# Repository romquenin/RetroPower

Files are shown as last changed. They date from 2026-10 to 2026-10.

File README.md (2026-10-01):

# RetroPower

Home Assistant-controlled power module for retro consoles, built around an ESP32-C3 — 2-layer PCB (KiCad), with a relay that emulates the console's power button for remote on/off.

## Two PCB versions

### `hardware/integrated/` — integrated version (recommended)
The ESP32-C3-Zero module (Waveshare, 18 castellated pins) is **soldered directly to the back of the PCB** — no flying wires. The antenna ends up on the outer edge of the board, completely clear of any copper/metal on both sides, for the best possible WiFi/Bluetooth reception.

- Dimensions: 53.335 x 32.75 mm
- Official KiCad DRC: 0 errors / 0 warnings (v4)
- See `README.md` in this folder for the changelog and the pin-spacing verification procedure to run before soldering the module for good.

### `hardware/compact/` — compact version (fallback)
The ESP32-C3-Zero module is connected via flying wires (not soldered directly onto the PCB). Immune to dimensional variation between modules — useful as a fallback if the integrated version ever runs into a physical compatibility issue.

- Dimensions: 40.45 x 32.75 mm
- Official KiCad DRC: 0 errors / 0 warnings (v11)
- See `README.md` and `WIRING.md` in this folder.

Each folder contains: the `.kicad_pcb`/`.kicad_pro` files, the gerbers (folder + zip), the component position file (`_pos.csv`), the BOM (`BOM.csv`), a rendered image of the routed board, and a `README.md` explaining the design choices.

## Bill of materials

Full per-reference BOM (with placement notes) is in each version's own `BOM.csv` (`hardware/integrated/BOM.csv` / `hardware/compact/BOM.csv`). Same components and values on both versions, except J1 (compact version only, header for the flying wires to the ESP32) and the ESP32 module itself (soldered directly on the integrated version, wired via J1 on the compact one).

**On the PCB:**

| Ref | Part | Package | Notes |
|---|---|---|---|
| U1 | ESP32-C3-Zero (Waveshare) | 18-pin castellated module, 2.54mm pitch | Integrated version only — soldered to the back of the PCB |
| K1 | HFD2/003-M-L2-D (Hongfa) | DIP-16 (10 real pins) | Bistable 2xRT relay |
| Q1, Q2 | AO3400A | SOT-23 | N-channel MOSFET |
| D1, D2 | 1N4148WS | SOD-123 | Flyback diodes (relay coils) |
| D3 | 1N5819WS | SOD-123 | Reverse-polarity protection on RAW_IN |
| R1, R2 | 100R | 0805, 1/4W 5% | Series gate resistors |
| R3, R4 | 10k | 0805, 1/4W 5% | Gate pulldowns |
| C1 | 100µF / 16V | SMD electrolytic, 6.3x5.4mm | — |
| C2 | 100nF | 0805 ceramic | HF decoupling on 3V3 |
| J1–J6 | 2.54mm pin headers | 2 to 5 pins, vertical | See each version's wiring notes |

**Off the PCB (external, per console):**

- A buck converter module (raw 12V/8V → regulated 3.3V) — any small off-the-shelf buck board rated for the console's raw voltage works; test it unloaded before wiring it in.
- Hookup wire:
  - **Power lines** (raw 12V/8V to/from the buck, regulated 3V3 to J2): 0.5mm²/20-21AWG is plenty for these currents.
  - **Signal/GPIO lines** (console switch tap to J4/J5, POWER_SENSE tap to J6): thinner wire is fine here, e.g. 30AWG — negligible current, easier to route inside the console's case.

## Firmware

`firmware/retropower_template.yaml` — generic ESPHome template, to be duplicated for each console (change `device_name` / `friendly_name`). Pinout used:

- GPIO0 — `POWER_SENSE` (reads the console's 3V3 rail)
- GPIO3 — `RELAY_SET` (pulse → turns on, via Q1)
- GPIO10 — `RELAY_RESET` (pulse → turns off, via Q2)

## Generation scripts (KiCad / Python)

`scripts/` contains the Python scripts (using the `pcbnew` API) used to generate and route each board, plus the verification scripts (clearance, holes, connectivity, board-edge clearance, silkscreen, component-body overlap) used alongside KiCad's official DRC.

- `scripts/integrated/`: `build_integrated.py` (placement + footprints), `route_integrated.py` (initial routing), `fix_net_integrated.py` (targeted routing fixes)
- `scripts/compact/`: `build_compact_v3.py`, `route_grid_compact5.py`
- `scripts/checks/`: verification scripts shared by both versions

Requires KiCad 7 (headless `pcbnew` API) and Python 3.

## How it works

The module emulates pressing the console's power button through two separate pulses (SET/RESET) driven by two MOSFETs (Q1/Q2) that control the two coils of a bistable relay (K1) — the relay stays in the chosen state with no continuous power draw. A sense tap (`POWER_SENSE`) lets the ESP32 read the console's actual power state for Home Assistant.

## Power supply

The buck converter (console's raw 12V/8V → regulated 3.3V) is **external**, not integrated onto the PCB. See each version's `README.md`/`WIRING.md` for the exact wiring (`J2` = regulated 3.3V input, `J3` = raw tap + reverse-polarity protection).

## Disclaimer

These files are provided as-is, with no warranty. Always re-run KiCad's official DRC before ordering a batch of PCBs, and check the 3V3 rail with a multimeter before soldering an ESP32 module in for good.

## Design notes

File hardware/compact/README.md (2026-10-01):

RetroPower - Central module, COMPACT version -- fix for 3 copper_edge_clearance errors
========================================================================
Dimensions: 40.45 x 32.75mm (UNCHANGED). Component layout UNCHANGED.
Schematic/wiring UNCHANGED (D3 remains correct, see previous version).

WHY THIS NEW VERSION
------------------------------------
Your last official DRC run found 3 [copper_edge_clearance] errors -- all
on the Q1_GATE net (the trace connecting R1, Q1 and R3), at three
different spots: (10.4, 0.2), (24.4, 0.2) and (4.8, 5.8). In all three
cases, KiCad measured only 0.025mm between this trace and the board
outline (Edge.Cuts), while the board's rules require 0.5mm.

WHAT THIS ACTUALLY MEANS
--------------------------------------
The "board outline" (Edge.Cuts) is the line the manufacturer's router (or
laser) follows to cut your board out of the raw copper/fiberglass panel.
This cut is never perfectly precise -- there's always a small mechanical
tolerance. If a copper trace runs too close to this cut line (here, 25
microns -- about the width of a fine hair), there's a real risk the
cutter "eats into" part of the trace, or even severs it completely,
without this necessarily being visible to the naked eye. Hence the 0.5mm
safety margin rule.

WHERE THIS CAME FROM
-------------------
My targeted fix tool (the one I use to repair a single copper trace
without touching the rest of the board) did have a safety margin near
the board outline, but it was only 0.3mm -- below the 0.5mm actually
required. Since the Q1_GATE net is precisely the one I had to repair
several times during the D3 fix (the board is very dense in that area,
squeezed between relay K1 and several other traces), it's the only one
that ended up going through that tool with an insufficient margin --
which explains why it alone was affected.

Digging further (checking that the fixed trace really respects 0.5mm
everywhere, not just at the 3 spots your DRC flagged), I found a second,
more subtle issue in that same tool: the safety margin near the edge
didn't account for a via's own size (a connection pad between the two
copper layers, 0.4mm radius) -- it only protected its center, not its
actual outline. A via could therefore have been allowed at a spot where
its own body still ran too close to the edge. Also fixed: the margin is
now computed separately for a trace (0.5mm + half the trace width) and
for a via (0.5mm + its actual radius).

WHAT WAS FIXED
------------------------
1. The safety margin near the board outline, in the targeted fix tool,
   was changed from 0.3mm to a value that always guarantees at least
   0.5mm of real copper clearance at the edge -- separately for traces
   and for vias (see above).
2. The Q1_GATE net was entirely ripped up and rerouted with this
   corrected margin. Since the area is very congested (the direct path
   between Q1 and R1/R3 is blocked on both sides by the already-placed
   3V3, GND and RESET_CTRL traces), it had to be routed with a finer
   calculation grid to find a path that respects both the 0.5mm board-
   edge margin AND the 0.2mm minimum trace/pad clearance -- both were
   possible to satisfy together, just not with the coarse calculation
   grid used until then.
3. A new verification tool was built specifically for this rule (none of
   my previous tools checked the board outline at all -- a complete
   blind spot, now covered). It first reproduced EXACTLY the 3 values
   from your official DRC (0.025mm at the same three coordinates) before
   I fixed anything, to make sure it was measuring the same thing as
   KiCad before relying on it to validate the fix.

WHAT WAS RE-VERIFIED (the whole board, not just Q1_GATE)
--------------------------------------------------------------------
- Distance to the board outline (new rule checked): 0 violations across
  the whole board (0 traces, 0 vias, 0 pads closer than 0.5mm from the
  edge).
- Electrical clearance (exact pad geometry, vias included): 0 violations
  across 558 elements.
- Real connectivity (correct copper layer everywhere): 0 open circuits,
  0 dangling ends.
- Hole-to-hole spacing: 0 violations across 82 holes.
- Silkscreen overlap: 0 overlaps.
- Component body overlap: 0 real overlaps (the 7 already-known and
  accepted 0.25-0.30mm close calls from the start of the project remain,
  confirmed harmless by your own DRC across several versions).

Nothing else changed on the board: same component placement, same
electrical schematic (D3 correct), same dimensions. Only the physical
path of the Q1_GATE trace changed to respect the edge safety margin.

WHAT'S LEFT TO DO BEFORE ORDERING
---------------------------------------------
1. IMPORTANT: re-run KiCad's official DRC on this fixed file -- as
   always, that check matters most.
2. Visually review the routing on screen, area by area (the Q1_GATE path
   is a bit more winding than before because of the very limited space
   around K1 -- that's normal and expected, it remains a continuous
   trace with 0 defects).
3. Measure the ESP32 board you're actually using to confirm the "ESP32
   zone" rectangle roughly matches.
4. The buck stays external and MUST be tested unloaded before wiring it
   in.
5. Check that 40.45 x 32.75mm fits the intended enclosure before
   ordering fabrication.
6. Before plugging in the ESP32 for the first time: measure the voltage
   on the PCB's 3V3 rail with a multimeter (between a 3V3 pad and a GND
   pad) BEFORE inserting the ESP32 module -- you should read ~3.3V, not
   ~12V (verification of the D3 fix, still valid).

FILES PROVIDED
-------------------
- RetroPower_Compact.kicad_pcb: the complete, fixed PCB (open in KiCad)
- RetroPower_Compact.kicad_pro: minimal project file
- gerbers_RetroPower_Compact.zip: Gerbers + drill + position file
- RetroPower_Compact_pos.csv: position/orientation of each component
- BOM.csv: component list (unchanged from the previous version)
- final_compact.png: visual render of the fixed routing

Board dimensions: 40.45 x 32.75 mm, no mounting holes.

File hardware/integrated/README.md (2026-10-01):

RetroPower - Central module, INTEGRATED version (ESP32-C3-Zero soldered to the BACK of the PCB)
====================================================================================
Dimensions: 53.335 x 32.75mm (the "compact" version with flying wires,
40.45 x 32.75mm, remains AVAILABLE AS A FALLBACK -- see below).

FIX v4 -- J4 reference label restored
--------------------------------------------------------------------
In v3, J4's reference had been hidden for lack of space. At the user's
request: reused the same treatment as J5/J6 just below (label offset to
the left of the connector instead of above it) -- same solution, same
visual result, J4 has its reference label back.
The whole board was fully rerouted and re-verified after this change (one
net touched by the new routing, Q2_GATE, was redone with a more generous
clearance): 0 violations across the 5 checks.

FIX v3 (official DRC run on v2) -- 3 warnings fixed
--------------------------------------------------------------------
1. [text_height] the "U1 -- MOUNT ON BACK" note was 0.6mm tall, below the
   0.8mm minimum required by the PCB's design rules.
2. [silk_over_copper] that same note, placed vertically in the narrow gap
   between U1 and K1 (0.85mm), overflowed onto K1's solder mask -- that
   gap is in fact too narrow for any text regardless of its size.
   -> Fixed: note shortened ("U1: MOUNT ON BACK OF PCB"), switched back
   to horizontal at 0.8mm, moved into the clear space BELOW U1 and ABOVE
   C1 (~1.585mm tall, plenty of room).
3. [silk_overlap] J4's reference field, repositioned to clear R1, was
   actually overlapping J4's own body -- the area around J4/R1/J5 is too
   tight in every direction to fit a label there.
   -> Fixed: J4's reference hidden (like U1's), purely cosmetic -- it
   stays in the BOM and the position file.

The whole board was re-verified and rerouted after these changes: 0
violations across the 5 checks (clearance, holes, connectivity, board
edge, silkscreen); the same already-known 0.25-0.30mm close calls between
component bodies (K1/J3/D3/D1, J5/J6) remain, identical to the previous
version.

WHAT CHANGED IN v2 COMPARED TO THE INITIAL v1
--------------------------------------------------------------------
Three changes compared to the previous integrated version:

1. MOUNTED ON THE BACK OF THE PCB (no longer on the component side)
   After discussion about pin orientation: the Waveshare datasheet that
   gives the pinout detail (5V/GND/3V3/GP0../GP21) is a view of the BACK
   of the module. Two mounting options are possible:
     - module's component side facing up (same side as K1, Q1...): this
       would have required MIRRORING this back view before placing the
       pads.
     - module's component side facing DOWN (soldered to the back of the
       PCB): the back view can be used AS-IS, with no mirroring.
   This second option is the one used here -- the pinout from the
   previous delivery was therefore correct, but ONLY for back-mounting,
   not component-side mounting as mistakenly stated at the time.
   Additional benefit: the component side of the PCB stays completely
   clear under the antenna (no trace or pad from any other component
   nearby), for the best possible RF isolation.
   Consequence: U1 has no silkscreen outline of its own (no outline or
   text printed on the back, to avoid extra JLCPCB manufacturing cost) --
   a note "U1 (ESP32-C3-Zero) -- MOUNT ON BACK OF PCB" is printed on the
   FRONT silkscreen, next to U1's location, so this isn't forgotten
   during assembly.

2. 2-ROW PIN SPACING CORRECTED (15.24mm instead of 18mm)
   The first estimate (18mm) was based on the module's total body width
   -- too large. You measured the real spacing via photo overlay
   (Photoshop, calibrated on the 2.54mm horizontal pitch, cross-checked
   against K1's footprint): ~15.43mm, very close to 15.24mm = 6 x 2.54mm
   (a "round" value on the same grid, likely the real manufacturer spec).
   This is the value used here. AS ALWAYS: to be confirmed with a new
   photo overlay once the physical PCB is received, before soldering the
   module for good (see the verification procedure below).

3. U1 REPOSITIONED ABOVE C1, PCB SHORTENED BY 10.615mm
   Thanks to the corrected pin spacing (U1 much more compact in height),
   U1 now fits above C1 without making the board taller. Its right edge
   (USB-C side) is aligned with C1's right edge. K1, Q1, Q2, D2, C1, C2,
   J2, J4, J5, J6 moved closer to U1 (offset reduced from 23.5mm to
   12.885mm); J3, D3, D1, R1 (just above K1) moved back a bit further
   (18.885mm) to clear U1 -- they remain X-overlapped with K1 but
   Y-separated, exactly as in the original layout already validated by
   the official DRC. Result: the board goes from 63.95mm to 53.335mm in
   length (-10.615mm).

MODULE ORIENTATION -- REMINDER
--------------------------------------------------
The module is rotated 90 deg relative to its "natural" position (USB-C
normally at the top on its product page): here, **USB-C points to the
right** (towards K1/the rest of the board) and the **antenna ends up on
the left**, on the board's outer edge -- the most clear spot possible
from any copper or metal, on BOTH sides of the PCB now (see point 1
above), for the best possible WiFi/Bluetooth reception.

U1 PINOUT (ESP32-C3-Zero module, mounted on the BACK of the PCB)
------------------------------------------
Viewed from the back of the PCB (the side where the module is soldered),
once soldered in the orientation described above (antenna on the left,
USB-C on the right):

  TOP row (pins 10 to 18, from left/antenna to right/USB-C):
    GP6 - GP7 - GP8 - GP9 - GP10 - GP18 - GP19 - GP20 - GP21

  BOTTOM row (pins 9 to 1, from left/antenna to right/USB-C):
    GP5 - GP4 - GP3 - GP2 - GP1 - GP0 - 3V3 - GND - 5V

Pin 1 (5V) marked by a square pad, bottom-right corner (near USB-C) --
same convention as every other connector on the board.

Connections used:
  Pin 3  (3V3, bottom row)  <- power from the 3.3V buck
  Pin 2  (GND, bottom row)  <- common ground
  Pin 4  (GP0, bottom row)  -> SENSE_MID (reads POWER_SENSE)
  Pin 7  (GP3, bottom row)  -> SET_CTRL (relay SET command)
  Pin 14 (GP10, top row)    -> RESET_CTRL (relay RESET command)

All other pins (1/5V, 5,6,8,9,10,11,12,13,15,16,17,18) remain
UNCONNECTED -- that's normal, they aren't used in this setup.

Powering through pin 3 rather than USB: this is the standard method for
this type of module (the "3V3(OUT)" pin is actually the output of the
onboard LDO regulator, but feeding it directly with an already-clean
3.3V supply -- our buck -- is common and safe practice, as long as the
5V pin stays unconnected at the same time).

Accepted side effect: GP10 is also the pin that drives the module's
built-in RGB LED (WS2812) -- it will therefore blink along with every
relay RESET command.

********************************************************************
* TO VERIFY BEFORE SOLDERING FOR GOOD -- PIN SPACING                *
********************************************************************
The 15.24mm figure used here comes from a photo-overlay measurement
(accurate, but not a physical measuring instrument). BEFORE soldering
the module onto this board for good:
  1. First solder the pin header onto the module's own castellated
     half-holes (not onto the PCB yet).
  2. Measure the REAL spacing between the two pin rows with calipers
     (center to center), OR redo a photo overlay once the physical PCB
     is in hand (same method as before: calibrate on the 2.54mm pitch,
     compare against the PCB).
  3. Compare against 15.24mm. If the difference is significant
     (>0.3-0.4mm), let me know before soldering onto the PCB -- the pads
     would need adjusting and a targeted reroute, which is quick to fix.

WHAT WAS VERIFIED ON THIS VERSION
-------------------------------------------
- Distance to the board outline (0.5mm required): 0 violations.
- Electrical clearance (exact pad geometry, vias included): 0 violations
  across 475 elements.
- Real connectivity: 0 open circuits, 0 dangling ends.
- Hole-to-hole spacing: 0 violations across 87 holes.
- Silkscreen overlap: 0 overlaps.
- Component body overlap: the same already-known and accepted
  0.25-0.30mm close calls from the original compact version (validated
  by the official DRC) remain -- nothing new introduced by this
  repositioning (checked component by component).

As always: this is my own verification, NOT a substitute for KiCad's
official DRC -- re-run it on this file before ordering.

YOU CAN ALWAYS GO BACK TO THE COMPACT VERSION
---------------------------------------------------
The flying-wire version (40.45 x 32.75mm, ESP32 module attached
separately) remains available and fully validated (official DRC 0/0) --
nothing has been removed or modified in those files.

WHAT'S LEFT TO DO BEFORE ORDERING
---------------------------------------------
1. The module fit-check test described above (the most important point
   for this version).
2. Re-run KiCad's official DRC on this file.
3. Check that 53.335 x 32.75mm fits the intended enclosure.
4. The buck stays external and MUST be tested unloaded before wiring it
   in.
5. Before soldering the ESP32-C3-Zero for good: measure the voltage on
   the PCB's 3V3 rail with a multimeter (between a 3V3 pad and a GND
   pad) BEFORE soldering the module in -- you should read ~3.3V, not
   ~12V.

FILES PROVIDED
-------------------
- RetroPower_Integrated.kicad_pcb: the complete PCB (open in KiCad)
- RetroPower_Integrated.kicad_pro: minimal project file
- gerbers_RetroPower_Integrated.zip: Gerbers + drill + position file
- RetroPower_Integrated_pos.csv: position/orientation of each component
- BOM.csv: component list (U1 detailed with its pinout)
- final_integrated.png: visual render of the routing

Board dimensions: 53.335 x 32.75 mm, no mounting holes.

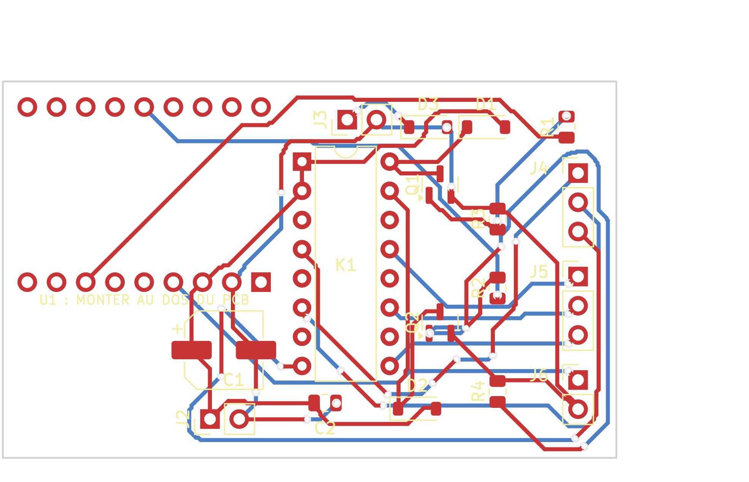
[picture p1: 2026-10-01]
hardware/integrated/final_integrated.png

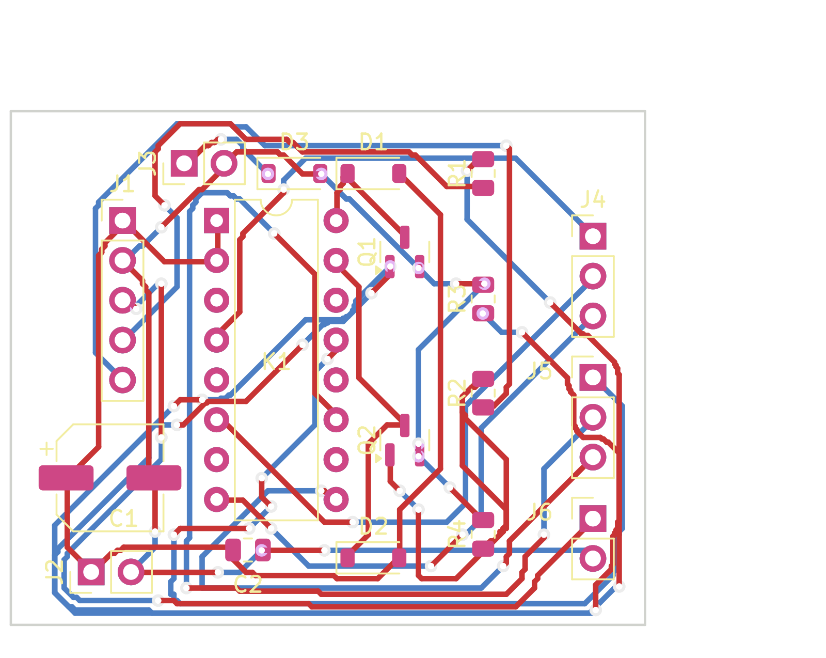
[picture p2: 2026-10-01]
hardware/compact/final_compact.png

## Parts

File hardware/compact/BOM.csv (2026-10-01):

Reference | Value | Footprint | Description
K1 | HFD2/003-M-L2-D | Package_DIP.pretty:DIP-16_W7.62mm | Bistable 2xRT relay (10 real pins on a DIP-16 grid -- pinout confirmed from the Hongfa datasheet)
Q1 | AO3400A | Package_TO_SOT_SMD:SOT-23 | N-channel MOSFET (drives coil SET)
Q2 | AO3400A | Package_TO_SOT_SMD:SOT-23 | N-channel MOSFET (drives coil RESET)
D1 | 1N4148WS (SOD-123) | Diode_SMD:D_SOD-123 | Flyback diode for coil SET
D2 | 1N4148WS (SOD-123) | Diode_SMD:D_SOD-123 | Flyback diode for coil RESET -- offset downward to create a real margin from K1's body (actual overlap found by the official DRC)
D3 | 1N5819WS (SOD-123) | Diode_SMD:D_SOD-123 | Reverse-polarity protection diode on RAW_IN (anode=RAW_IN | cathode=GND -- FIXED | it was mistakenly wired to 3V3) -- on the same line as D1/R1 | to the right of J3
R1 | 100R | Resistor_SMD:R_0805_2012Metric | Series gate resistor for Q1 -- real value validated on the SNES -- aligned on the same line as D1
R2 | 100R | Resistor_SMD:R_0805_2012Metric | Series gate resistor for Q2 -- real value validated on the SNES
R3 | 10k | Resistor_SMD:R_0805_2012Metric | Gate pulldown for Q1 -- real value validated on the SNES
R4 | 10k | Resistor_SMD:R_0805_2012Metric | Gate pulldown for Q2 -- real value validated on the SNES
C1 | 100uF/16V (SMD only) | Capacitor_SMD:CP_Elec_6.3x5.4 | SMD only -- J1 pin 1 aligned with K1 pin 1 | C1 follows
C2 | 100nF | Capacitor_SMD:C_0805_2012Metric | HF decoupling on 3V3 (kept -- already present and validated on the SNES setup)
J1 | ESP32 (flying wires) -- 5 pins | Connector_PinHeader_2.54mm:PinHeader_1x05_P2.54mm_Vertical | 3V3 / GND / SENSE(GPIO0) / SET(GPIO3) / RESET(GPIO10) -- pin 1 aligned with K1 pin 1
J2 | Buck 3V3 OUT (2 pins) | Connector_PinHeader_2.54mm:PinHeader_1x02_P2.54mm_Vertical | 3V3 / GND -- under C1
J3 | Raw power tap to buck (2 pins) | Connector_PinHeader_2.54mm:PinHeader_1x02_P2.54mm_Vertical | RAW_IN / GND -- at the top | above J1 | parallel to J2
J4 | Console switch pole 1 (3 pins) | Connector_PinHeader_2.54mm:PinHeader_1x03_P2.54mm_Vertical | SW_COM / SW_NC / SW_NO
J5 | Relay pole 2 -- free/reserved (3 pins) | Connector_PinHeader_2.54mm:PinHeader_1x03_P2.54mm_Vertical | SW2_COM / SW2_NC / SW2_NO
J6 | Console POWER_SENSE tap -- already at 3.3V (2 pins) | Connector_PinHeader_2.54mm:PinHeader_1x02_P2.54mm_Vertical | SENSE / GND -- wired directly | no voltage divider

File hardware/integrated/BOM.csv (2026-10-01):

Reference | Value | Footprint | Description
K1 | HFD2/003-M-L2-D | Package_DIP.pretty:DIP-16_W7.62mm | Bistable 2xRT relay (10 real pins on a DIP-16 grid -- pinout confirmed from the Hongfa datasheet)
Q1 | AO3400A | Package_TO_SOT_SMD:SOT-23 | N-channel MOSFET (drives coil SET)
Q2 | AO3400A | Package_TO_SOT_SMD:SOT-23 | N-channel MOSFET (drives coil RESET)
D1 | 1N4148WS (SOD-123) | Diode_SMD:D_SOD-123 | Flyback diode for coil SET
D2 | 1N4148WS (SOD-123) | Diode_SMD:D_SOD-123 | Flyback diode for coil RESET
D3 | 1N5819WS (SOD-123) | Diode_SMD:D_SOD-123 | Reverse-polarity protection diode on RAW_IN (anode=RAW_IN | cathode=GND)
R1 | 100R | Resistor_SMD:R_0805_2012Metric | Series gate resistor for Q1
R2 | 100R | Resistor_SMD:R_0805_2012Metric | Series gate resistor for Q2
R3 | 10k | Resistor_SMD:R_0805_2012Metric | Gate pulldown for Q1
R4 | 10k | Resistor_SMD:R_0805_2012Metric | Gate pulldown for Q2
C1 | 100uF/16V (SMD only) | Capacitor_SMD:CP_Elec_6.3x5.4 | SMD only -- right edge aligned with U1's
C2 | 100nF | Capacitor_SMD:C_0805_2012Metric | HF decoupling on 3V3
U1 | ESP32-C3-Zero (Waveshare) | Custom footprint -- 18 THT pins 2.54mm (9+9) | SOLDERED TO THE BACK OF THE PCB (opposite side from the other components -- no flying wires or J1). USB-C facing right (towards K1) / antenna facing left (board's outer edge | clear of copper on both sides). Positioned above C1 | right edge aligned. Pin 3 (3V3 OUT) <- buck power; pin 2 (GND); pin 4 (GP0) -> SENSE_MID; pin 7 (GP3) -> SET_CTRL; pin 14 (GP10) -> RESET_CTRL | shared with the module's WS2812 RGB LED (accepted). Pin 1 (5V) intentionally left unconnected. 2-ROW PIN SPACING: 15.24mm (measured via photo overlay | calibrated on the 2.54mm pitch -- TO BE CONFIRMED by direct measurement once the PCB is received | see README).
J2 | Buck 3V3 OUT (2 pins) | Connector_PinHeader_2.54mm:PinHeader_1x02_P2.54mm_Vertical | 3V3 / GND -- under C1
J3 | Raw power tap to buck (2 pins) | Connector_PinHeader_2.54mm:PinHeader_1x02_P2.54mm_Vertical | RAW_IN / GND
J4 | Console switch pole 1 (3 pins) | Connector_PinHeader_2.54mm:PinHeader_1x03_P2.54mm_Vertical | SW_COM / SW_NC / SW_NO -- SW_NC can be left unwired if your original switch only uses COM+NO
J5 | Relay pole 2 -- free/reserved (3 pins) | Connector_PinHeader_2.54mm:PinHeader_1x03_P2.54mm_Vertical | SW2_COM / SW2_NC / SW2_NO
J6 | Console POWER_SENSE tap -- already at 3.3V (2 pins) | Connector_PinHeader_2.54mm:PinHeader_1x02_P2.54mm_Vertical | SENSE / GND -- J6's GND doesn't need to be wired separately (same GND net as J3/J2)

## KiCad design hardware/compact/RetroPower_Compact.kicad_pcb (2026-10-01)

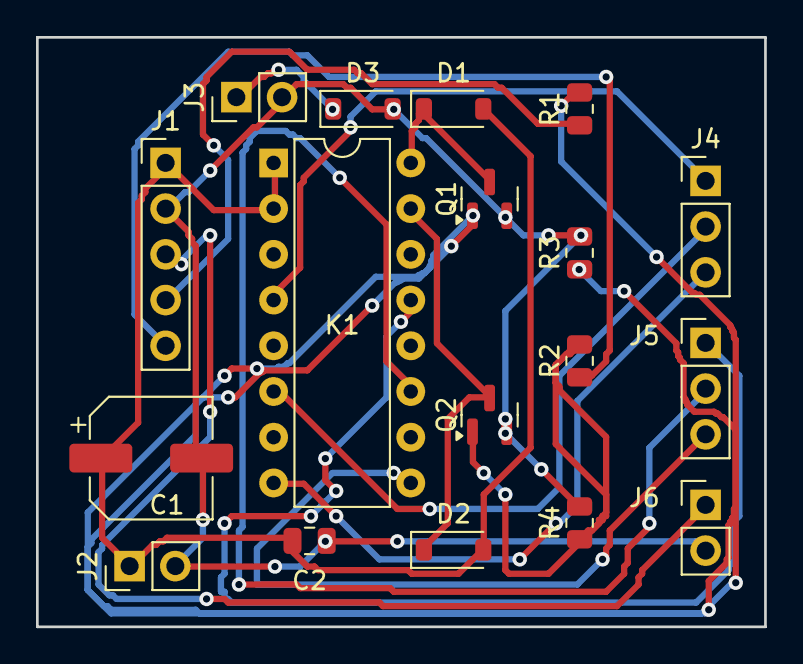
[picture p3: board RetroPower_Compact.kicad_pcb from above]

Board: 2 copper layers, 40.5 x 32.8 mm, 18 parts (0 on the bottom side), 16 nets.

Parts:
C1: 100uF/16V (CMS); CP_Elec_6.3x5.4
C2: 100nF; C_0805_2012Metric
D1, D2: 1N4148WS (SOD-123); D_SOD-123
D3: 1N5819WS (SOD-123); D_SOD-123
J1: ESP32 (fils volants); PinHeader_1x05_P2.54mm_Vertical
J2: Buck 3V3 OUT; PinHeader_1x02_P2.54mm_Vertical
J3: Tap alim brute (vers buck); PinHeader_1x02_P2.54mm_Vertical
J4: Switch console (pole 1); PinHeader_1x03_P2.54mm_Vertical
J5: Pole 2 relais (libre/reserve); PinHeader_1x03_P2.54mm_Vertical
J6: POWER_SENSE tap console (deja 3.3V); PinHeader_1x02_P2.54mm_Vertical
K1: HFD2/003-M-L2-D; DIP-16_W7.62mm
Q1, Q2: AO3400A; SOT-23
R1, R2: 100R; R_0805_2012Metric
R3, R4: 10k; R_0805_2012Metric

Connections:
3V3: C1.1, C2.1, D1.2, D2.2, J1.1, J2.1, K1.1, K1.2
COIL_RESET_B: D2.1, K1.15, Q2.3
COIL_SET_B: D1.1, K1.16, Q1.3
GND: C1.2, C2.2, D3.2, J1.2, J2.2, J3.2, J6.2, Q1.2, Q2.2, R3.2, R4.2
Q1_GATE: Q1.1, R1.2, R3.1
Q2_GATE: Q2.1, R2.2, R4.1
RAW_IN: D3.1, J3.1
RESET_CTRL: J1.5, R2.1
SENSE_MID: J1.3, J6.1
SET_CTRL: J1.4, R1.1
SW2_COM: J5.1, K1.13
SW2_NC: J5.2, K1.11
SW2_NO: J5.3, K1.9
SW_COM: J4.1, K1.4
SW_NC: J4.2, K1.6
SW_NO: J4.3, K1.8

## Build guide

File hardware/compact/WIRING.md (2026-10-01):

========================================================================
   RetroPower -- Wiring summary (J1, J2, J3, J4, J6)
========================================================================
Board: RetroPower_Compact (compact version, 40.45 x 32.75mm)
Connectors: male/female headers, 2.54mm pitch (flying wires)

------------------------------------------------------------------------
  HOW TO IDENTIFY PIN 1 ON EACH CONNECTOR
------------------------------------------------------------------------
On every connector on this board, pin 1 can be identified TWO ways,
both visible to the naked eye on the PCB:

  1. Pin 1's COPPER PAD is SQUARE (a solid "square"). Every other pin on
     the same connector has a ROUND pad. This is the most reliable
     marker -- it stays visible even after soldering.

  2. The silkscreen outline (the white/yellow drawing around the
     connector) has a SMALL CORNER CUT OFF (chamfer) on pin 1's side.
     This is the classic marker used on most PCBs.

This is exactly what you spotted on J6 and J4: the square = pin 1, the
small cut corner on the outline = the same marker, pin 1 side.

------------------------------------------------------------------------
  J1 -- To the ESP32 module (flying wires), 5 pins
------------------------------------------------------------------------
  Pin 1 (square): 3V3          -> 3.3V power to the ESP32
  Pin 2          : GND          -> common ground
  Pin 3          : SENSE_MID    -> ESP32's GPIO0 (reads POWER_SENSE)
  Pin 4          : SET_CTRL     -> ESP32's GPIO3 (relay SET command)
  Pin 5          : RESET_CTRL   -> ESP32's GPIO10 (relay RESET command)

  Board orientation: vertical connector, pins running from top (pin 1)
  to bottom (pin 5), on the left edge of the board, next to relay K1.

------------------------------------------------------------------------
  J2 -- Buck converter output (regulated 3.3V), 2 pins
------------------------------------------------------------------------
  Pin 1 (square): 3V3   -> buck's 3.3V output, to the PCB
  Pin 2          : GND   -> common ground

  Board orientation: horizontally-laid connector, under capacitor C1
  (bottom of the board). Pin 1 on the left, pin 2 on the right.

------------------------------------------------------------------------
  J3 -- Raw power tap (to the buck's input), 2 pins
------------------------------------------------------------------------
  Pin 1 (square): RAW_IN -> raw 12V tapped from the console, TO the
                            buck's input (protected by diode D3)
  Pin 2          : GND    -> common ground

  Board orientation: horizontally-laid connector, at the top of the
  board, above J1. Pin 1 on the left, pin 2 on the right.

------------------------------------------------------------------------
  J4 -- Console's original switch (relay pole 1), 3 pins
------------------------------------------------------------------------
  Pin 1 (square): SW_COM  -> original switch's common point
  Pin 2          : SW_NC   -> normally-closed contact (NC)
  Pin 3          : SW_NO   -> normally-open contact (NO)

  Board orientation: vertical connector, on the right edge of the board.
  Pin 1 at the top, pin 3 at the bottom.

  Reminder (confirmed from the Hongfa datasheet): relay K1 pole 1 =
  COM pin 4, NC pin 6, NO pin 8.

------------------------------------------------------------------------
  J6 -- Console POWER_SENSE tap (already at 3.3V), 2 pins
------------------------------------------------------------------------
  Pin 1 (square): SENSE_MID -> same signal as GPIO0/J1.3 (connected
                               directly to the console's internal 3.3V
                               rail, with NO voltage divider -- already
                               validated on your SNES)
  Pin 2          : GND       -> common ground

  Board orientation: vertical connector, on the right edge of the board,
  below J4. Pin 1 at the top, pin 2 at the bottom.

------------------------------------------------------------------------
  QUICK SUMMARY (overview)
------------------------------------------------------------------------
  J1 (5 pins): 3V3 - GND - SENSE_MID - SET_CTRL - RESET_CTRL
  J2 (2 pins): 3V3 - GND
  J3 (2 pins): RAW_IN - GND
  J4 (3 pins): SW_COM - SW_NC - SW_NO
  J6 (2 pins): SENSE_MID - GND

  Note: J1.3 and J6.1 carry the SAME electrical signal (SENSE_MID) --
  that's normal, they're two different access points to the same wire.

  (J5, not needed here, is relay pole 2 -- free/reserved, same pins as
  J4 but on SW2_COM/SW2_NC/SW2_NO.)
========================================================================

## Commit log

2026-10-01 Add RetroPower hardware (Integrated v4 + Compact v11), firmware template and build scripts
    Two DRC-clean (0 errors/0 warnings) 2-layer ESP32-C3 power control PCBs for
    Home Assistant integration with retro consoles, plus the ESPHome firmware
    template and the KiCad pcbnew generation/verification scripts used to build
    and route them.
    Claude-Session: https://claude.ai/code/session_01GF2MRZuK9gMJfPudxHLri7
    [BOM.csv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]
2026-10-01 Translate README/notes/BOM files to English
    Rename LISEZMOI.txt -> README.md and BRANCHEMENTS.txt -> WIRING.md in
    each hardware folder, translate their content and the BOM.csv
    descriptions, and rewrite the root README in English.
    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
    [BOM.csv]
2026-10-01 Add bill of materials section to the root README
    Summarize on-board and external components needed to build either board
    version, with a link to each version's detailed BOM.csv.
    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
2026-10-01 Clarify wire gauge recommendations in the BOM section
    Split power wiring (0.5mm2/20-21AWG) from signal/GPIO wiring (thinner
    30AWG is fine for the switch and POWER_SENSE taps).
    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
2026-10-14 Fix diode orientation docs, English firmware template, assembly notes
    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
2026-10-20 Add per-console notes, 100 ms pulses and boot relay reset to firmware template
    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
2026-10-22 Add PlayStation 2 (fat) notes and firmware for momentary power button
    Document the SCPH-30004R / GH-015 power button ribbon measurements, add a
    press-based ESPHome config (short press = on / reset, long press = off) with
    a Reset button, and index the console in docs/consoles.
    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
2026-10-23 Add Wi-Fi Toslink switch side project (CSL 41811, ESPHome)
    Documents the IR-jack mod that lets Home Assistant select the inputs of a
    CSL 41811 Toslink switch: measured jack pads, NEC codes, MOSFET emitter
    wiring, pitfalls, and an ESPHome firmware for a D1 mini.
    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
2026-10-23 Toslink project: explain how to read the IR codes, add reader wiring diagram
    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
2026-10-24 PS2: 100 ms coil pulses, Force off button, note that reset is disabled with a hard drive
    Firmware now matches the tested one (100 ms pulses, Force off). The PS2 docs
    explain that the console disables its reset button once a hard drive is
    connected (link to the upstream issue) and why 30 ms pulses were not reliable.
    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
2026-10-24 PS2: power-off press 4500 ms (3000 ms was not always enough)
    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
2026-11-01 README: require the ESP32-C3-Zero version with the isolated antenna
    Claude-Session: https://claude.ai/code/session_01WuCcZ2QLNg2KUp6uHhqiqu
2026-11-01 README: add ESP32-C3-Zero pin order and pins used
    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
2026-11-01 README: diode orientation for D1/D2 and D3
    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
2026-11-04 docs: second architecture (no relay) + 7 new console write-ups
    Consoles with a soft / momentary / touch power button do not need the
    RetroPower PCB at all: a single switching device across the button is
    enough. Document that build alongside the relay one.
    New:
    - docs/soft-power-buttons.md: relay vs single device, PhotoMOS AQY210EH
    wiring and DIP-4 pinout, the MOSFET alternative and its two failure
    modes, powering the ESP, sense and divider, bare ESP-12F variant with
    its boot-resistor table
    - docs/consoles/ps1.md: two-pole switch on the low-voltage side (J4+J5),
    USB-powered ESP, and the USB-C PSU video-noise experiment
    - docs/consoles/ps3.md: everything on the DSW-001 10-pin connecto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
2026-11-04 Xbox OG: working install (D1 mini + PhotoMOS)
    The front power button just shorts the SMC's power-button line to ground,
    so one PhotoMOS across it is enough. Validated: works from Home Assistant
    and from the console's own button.
    - firmware/retropower_xbox_og.yaml: GPIO4 output, GPIO14 sense, 300 ms
    toggle press, static .245
    - docs/consoles/xbox-og.md: per-revision table for the standby and sense
    rails (3.3 V standby on 1.0-1.5, 5 V on 1.6), the motherboard-side tap,
    and the wrong-ground-pin pitfall that cost the first attempt
    - indexes updated
    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
2026-11-05 Wii U: working install (bare ESP-12F + PhotoMOS)
    Soldered straight to the motherboard test points, first attempt. Works
    from Home Assistant and from the console's own power button.
    Points actually used, replacing the ranked WiiUBrew candidate list:
    - VCC on TP22 (WiiUBrew documents TP122 for the always-on 3.3 V — noted,
    but TP22 is what was measured here), GND on TP164
    - power switch on TP70
    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
2026-11-05 Wii: working install — the active-high power button
    Bare ESP-12F + PhotoMOS, validated from Home Assistant and from the
    console's own button. The last console of the set.
    Points used, all on side A:
    - VCC on TP204. TP110 is also always-on 3.3 V but cannot carry the
    module: the console lost video and the ESP did not start.
    - sense on the pad silkscreened "3.3V" above R113 (main rail)
    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
